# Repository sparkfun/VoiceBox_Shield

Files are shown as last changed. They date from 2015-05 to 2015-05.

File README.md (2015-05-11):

SparkFun VoiceBox Shield
========================================

SparkFun VoiceBox Shield

[*SparkFun VoiceBox Shield (DEV-10661)*](https://www.sparkfun.com/products/10661)

The SparkFun VoiceBox Shield can be mounted on top of your Arduino board to give it access to all of the capabilities of the SpeakJet voice and sound synthesizer. 
The Voice Box Shield uses the SpeakJet chip to convert serial commands into a great robot-sounding voice.

Repository Contents
-------------------

* **/Firmware** - Example code 
* **/Hardware** - Eagle design files (.brd, .sch)
* **/Production** - Production panel files (.brd)

Documentation
--------------
* **[Hookup Guide](https://www.sparkfun.com/tutorials/285)** - Basic hookup guide for the VoiceBox Shield.
* **[SparkFun Fritzing repo](https://github.com/sparkfun/Fritzing_Parts)** - Fritzing diagrams for SparkFun products.
* **[SparkFun 3D Model repo](https://github.com/sparkfun/3D_Models)** - 3D models of SparkFun products. 

License Information
-------------------
This product is _**open source**_! 

The **hardware** is released under [Creative Commons ShareAlike 4.0 International](https://creativecommons.org/licenses/by-sa/4.0/).

The **code** is beerware; if you see me (or any other SparkFun employee) at the local, and you've found our code helpful, please buy us a round!

Please use, reuse, and modify these files as you see fit. Please maintain attribution to SparkFun Electronics and release anything derivative under the same license.

Distributed as-is; no warranty is given.

- Your friends at SparkFun.

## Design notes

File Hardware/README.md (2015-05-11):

SparkFun <PRODUCT NAME> Design Files
=====================================

The .sch and .brd files hare are Eagle CAD schematic and PCB design files from SparkFun Electronics.
A freeware version of Eagle can be found [here](http://www.cadsoftusa.com/download-eagle/freeware/). 

License
---------
This product is open source! 
The hardware is released under [Creative Commons ShareAlike 4.0 International](https://creativecommons.org/licenses/by-sa/4.0/).

Please use, reuse, and modify these files as you see fit. Please maintain attribution to SparkFun Electronics and release anything derivative under the same license.

Distributed as-is; no warranty is given.

- Your friends at SparkFun.

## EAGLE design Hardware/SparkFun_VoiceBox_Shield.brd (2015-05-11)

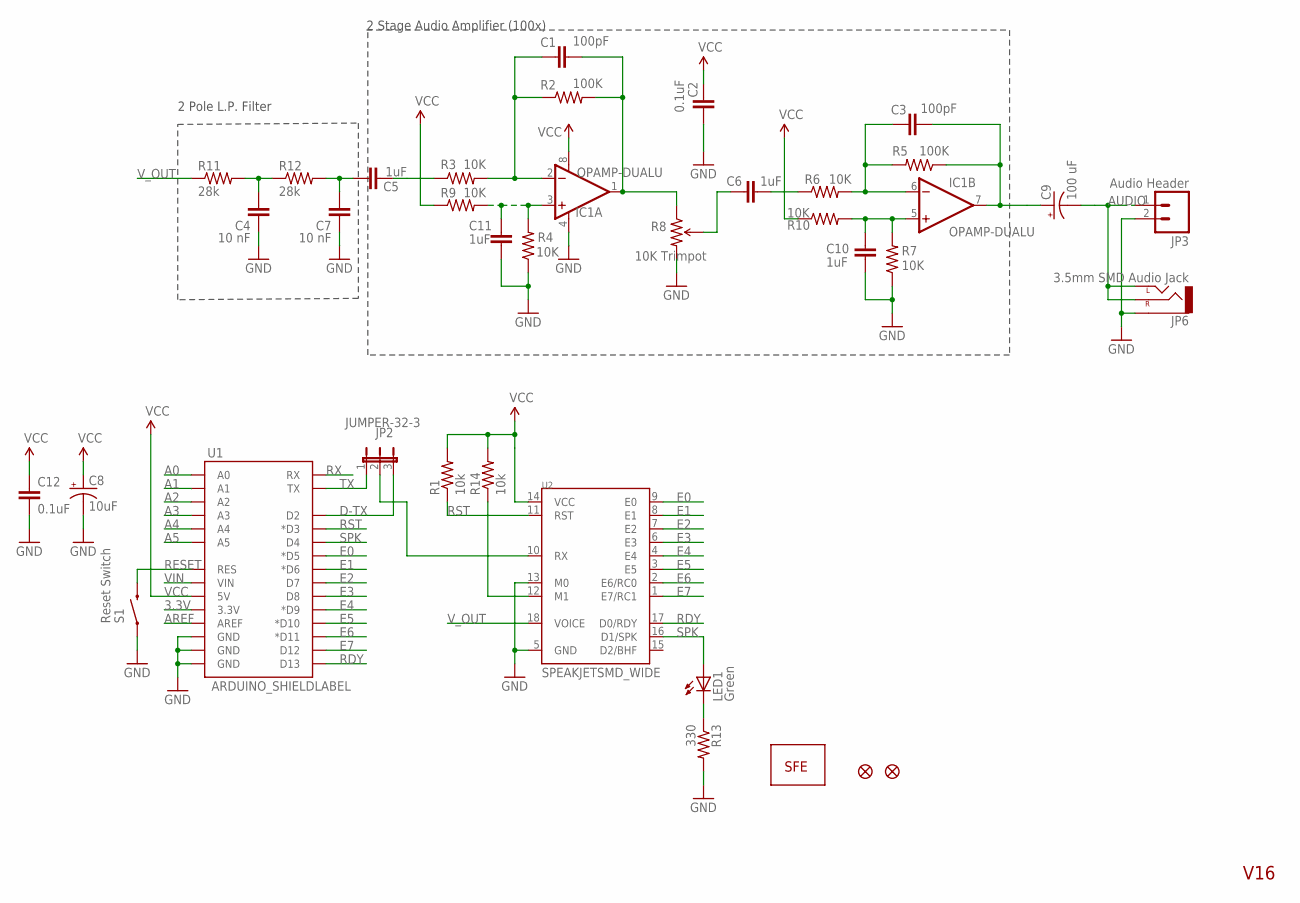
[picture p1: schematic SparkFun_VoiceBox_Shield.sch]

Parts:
C1, C3: 100pF; 0603-CAP
C2, C12: 0.1uF; 0603-CAP
C4, C7: 10 nF; 0603-CAP
C5, C6, C10, C11: 1uF; 0603-CAP
C8: 10uF; EIA3216
C9: 100 uF; EIA7343
IC1: OPAMP-DUALU; SO08
JP1: LOGO-SFENEW; SFE-NEW-WEBLOGO
JP2: JUMPER-32-3; SJ_3_PASTE2&3
JP3: Audio Header; 1X02
JP4, JP5: FIDUCIAL1X2; FIDUCIAL-1X2
JP6: 3.5mm SMD Audio Jack; AUDIO-JACK-3.5MM-SMD
LED1: Green; LED-0603
R1, R14: 10k; 0603-RES
R2, R5: 100K; 0603-RES
R3, R4, R6, R7: 10K; 0603-RES
R8: 10K Trimpot; TRIMPOT-3MM
R9, R10: 10K; 0603
R11, R12: 28k; 0603-RES
R13: 330; 0603-RES
S1: Reset Switch; TACTILE_SWITCH_SMD
U1: ARDUINO_SHIELDLABEL; DUEMILANOVE_SHIELD
U2: SPEAKJETSMD_WIDE; SO-18W

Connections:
3.3V: U1.3.3V
A0: U1.A0
A1: U1.A1
A2: U1.A2
A3: U1.A3
A4: U1.A4
A5: U1.A5
AREF: U1.AREF
AUDIO: C9.C (-), JP3.1, JP6.RING (RIGHT), JP6.TIP (LEFT)
D-TX: JP2.3, U1.D2
E0: U1.D5 (*D5), U2.9 (E0)
E1: U1.D6 (*D6), U2.8 (E1)
E2: U1.D7, U2.7 (E2)
E3: U1.D8, U2.6 (E3)
E4: U1.D9 (*D9), U2.4 (E4)
E5: U1.D10 (*D10), U2.3 (E5)
E6: U1.D11 (*D11), U2.2 (E6/RC0)
E7: U1.D12, U2.1 (E7/RC1)
GND: C2.2, C4.1, C7.1, C8.C (-), C10.2, C11.2, C12.2, IC1.4 (V-), JP3.2, JP6.SLEEVE, R4.1, R7.1, R8.3 (CW), R13.2, S1.1, U1.GND@0 (GND), U1.GND@1 (GND), U1.GND@2 (GND), U2.5 (GND), U2.13 (M0)
IN1: C5.2, R3.1
unnamed: JP2.2, U2.10 (RX)
unnamed: C1.1, IC1.2 (-IN), R2.1, R3.2
unnamed: C6.1, R6.1
unnamed: C6.2, R8.2 (WIPER)
unnamed: C3.1, IC1.6 (-IN), R5.2, R6.2
unnamed: C10.1, IC1.5 (+IN), R7.2, R10.2
unnamed: C11.1, IC1.3 (+IN), R4.2, R9.2
unnamed: C4.2, R11.2, R12.1
unnamed: C5.1, C7.2, R12.2
unnamed: LED1.C, R13.1
unnamed: R14.1, U2.12 (M1)
OUT1: C1.2, IC1.1 (OUT), R2.2, R8.1 (CCW)
RDY: U1.D13, U2.17 (D0/RDY)
RESET: S1.3 (2), U1.RES
RST: R1.1, U1.D3 (*D3), U2.11 (RST)
RX: U1.RX
SPK: LED1.A, U1.D4, U2.16 (D1/SPK)
SPK+: C3.2, C9.A (+), IC1.7 (OUT), R5.1
TX: JP2.1, U1.TX
VCC: C2.1, C8.A (+), C12.1, IC1.8 (V+), R1.2, R9.1, R10.1, R14.2, U1.5V, U2.14 (VCC)
VIN: U1.VIN
V_OUT: R11.1, U2.18 (VOICE)

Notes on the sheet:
2 Pole L.P. Filter
2 Stage Audio Amplifier (100x)
V16

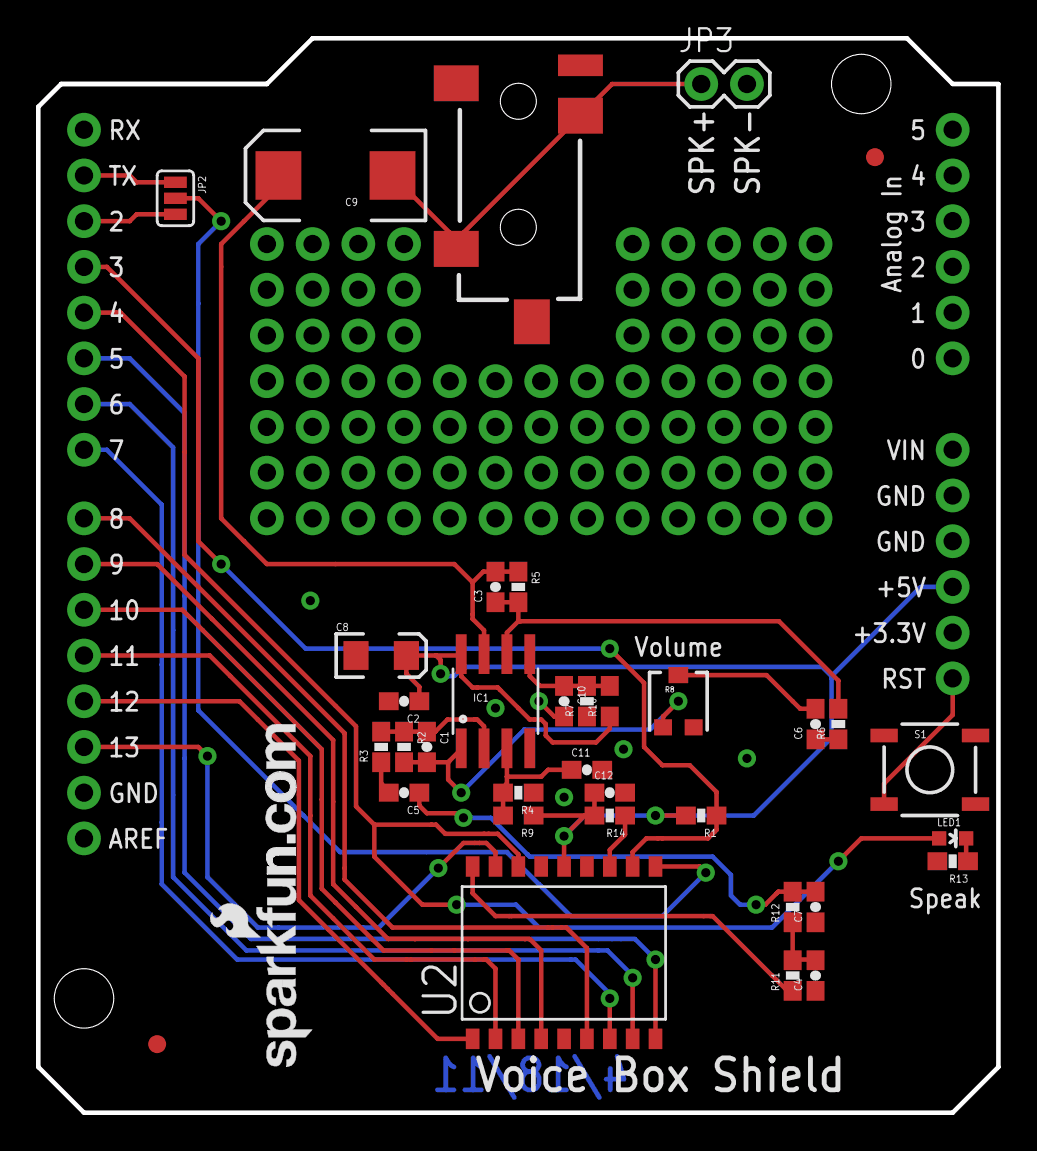
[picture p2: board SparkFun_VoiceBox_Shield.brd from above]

Board: 2 copper layers, 53.3 x 59.7 mm, 37 parts (0 on the bottom side), 32 nets.

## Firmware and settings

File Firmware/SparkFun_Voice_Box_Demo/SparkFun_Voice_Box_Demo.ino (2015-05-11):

/*
Voice Box Demo Sketch
Written by Ryan Owens
SparkFun Electronics

Uses the Voice Box Shield from SparkFun to send the message "All your base are belong to us" and a series
of robot sounds to the SpeakJet chip on the shield. 

A speaker can be plugged directly into the SPK+ and - pins on the shield.

*/

//Soft serial library used to send serial commands on pin 2 instead of regular serial pin.
#include <SoftwareSerial.h>

//Define the Pin Numbers for the sketch.
#define E0  5
#define E1  6
#define E2  7
#define E3  8
#define E4  9
#define E5  10
#define E6  11
#define E7  12

#define RDY  13
#define RES  3
#define SPK  4

#define txPin  2

//Create a SoftSerial Objet
SoftwareSerial speakjet = SoftwareSerial(0, txPin);

//The message array contains the command for sounds to be sent in order to inunciate the words "All your base belong to us." Check the SpeakJet Manual for more information
//on producing words
                                                  //All              Your         Base                 Are     Belong                       to          us
char message[] = {20, 96, 21, 114, 22, 88, 23, 5, 8, 135, 8, 146, 5, 128, 153, 5, 170, 154, 8, 188, 5, 152, 5, 170, 8,128,146,8,135,8,144,5,8,191,162,5,8,134,187};

//The sounds array contains the commands to send robot sounds to the SpeakJet chip.
char sounds[] = {200, 201, 202, 203, 220, 221, 222};

void setup()  
{
  //Configure the pins for the SpeakJet module
  pinMode(txPin, OUTPUT);
  pinMode(SPK, INPUT);
  
  //Set up a serial port to talk from Arduino to the SpeakJet module on pin 3.
  speakjet.begin(9600);    
  
  //Configure the Ready pin as an input
  pinMode(RDY, INPUT);
  
  //Configure Reset line as an output
  pinMode(RES, OUTPUT);
       
  //Configure all of the Event pins as outputs from Arduino, and set them Low.
  for(int i=E0; i<=E7; i++)
  {
    pinMode(i, OUTPUT);
    digitalWrite(i, LOW);
  }
  
  //All I/O pins are configured. Reset the SpeakJet module
  digitalWrite(RES, LOW);
  delay(100);
  digitalWrite(RES, HIGH);
  
}

void loop()
{  
  //Send "All Your Base are Belong to Us" to the SpeakJet module
  speakjet.print(message);
  //Wait before sending the next string.
  delay(3000);    
  //Send the robotic sounds to the module.
  speakjet.print(sounds);
  while(1);
}
